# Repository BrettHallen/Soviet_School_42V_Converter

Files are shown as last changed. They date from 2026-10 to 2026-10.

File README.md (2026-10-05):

# Soviet School 42V Converter
Convert Australian 230VAC power to Soviet 42VAC for computers & calculators.<br>

The Soviet had a low-voltage (42V) power supply available that used a special plug & socket (розетка 42В).<br>

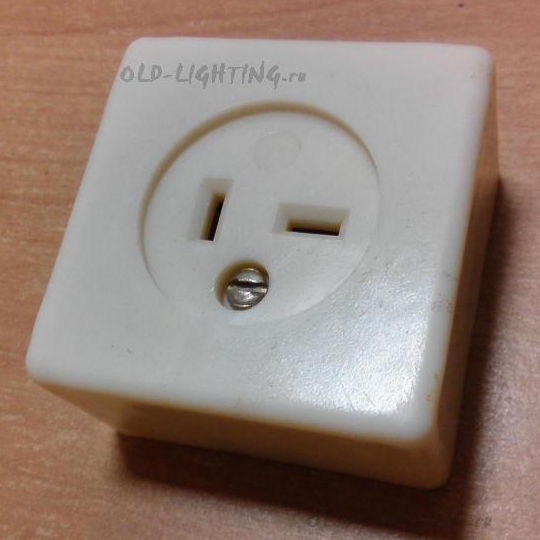
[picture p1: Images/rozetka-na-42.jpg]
Soviet LV socket


This was used by calculators such as the «Электроника МКШ-2» and computers such as the «Электроника МС0511».<br>

This appears similar to the Clipsal 402/32 (socket) and 492/32 (plug) available in Australia for low voltage requirements.<br>

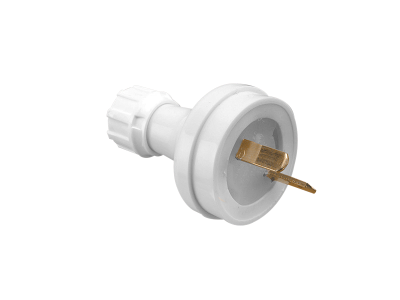
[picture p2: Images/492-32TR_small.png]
Clipsal plug


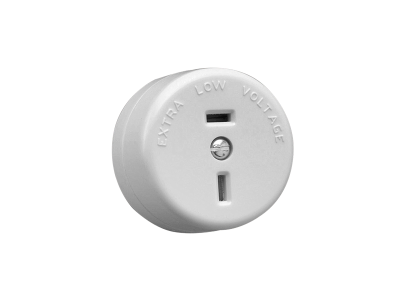
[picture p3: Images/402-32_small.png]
Clipsal socket


My idea was to create a simple 230VAC-to-42VAC step-down power supply with matching socket.<br>

My initial design will be using the Triad Magentics FP40-600 transformer.<br>

I'm not sure if the Soviet plug will fit the Australian socket, but the plug can always be replaced.<br>

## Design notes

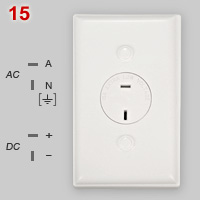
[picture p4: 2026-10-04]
Images/Clipsal_405-32_socket.jpg

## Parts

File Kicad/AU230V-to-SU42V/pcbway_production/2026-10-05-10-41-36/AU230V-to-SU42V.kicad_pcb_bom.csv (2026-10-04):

Designator | Quantity | Value | Footprint | Package | MPN | DNP | Mount_Type | Description | Height | Mouser Part Number | Mouser Price/Stock | Manufacturer_Name
F1 | 1 | 200mA T 250V | Fuseholder_Clip-5x20mm_Littelfuse_111_Inline_P20.00x5.00mm_D1.05mm_Horizontal |  |  |  | tht | Fuse
J1 | 1 | 230VAC Input | TJC1-2A |  |  |  | tht | C14 Plug, 10A max
J2 | 1 | 42VAC Output | TJC1-2A |  |  |  | tht | Generic connector, single row, 01x02, script generated (kicad-library-utils/schlib/autogen/connector/)
T1 | 1 | FP40-600 | FP40600 |  | FP40-600 |  | tht | Max. power 24VA, primary voltage 230V, secondary voltage 40Vct @ 600mA | 34.925 | 553-FP40-600 | https://mou.sr/4dQkbfw | Triad Magnetics

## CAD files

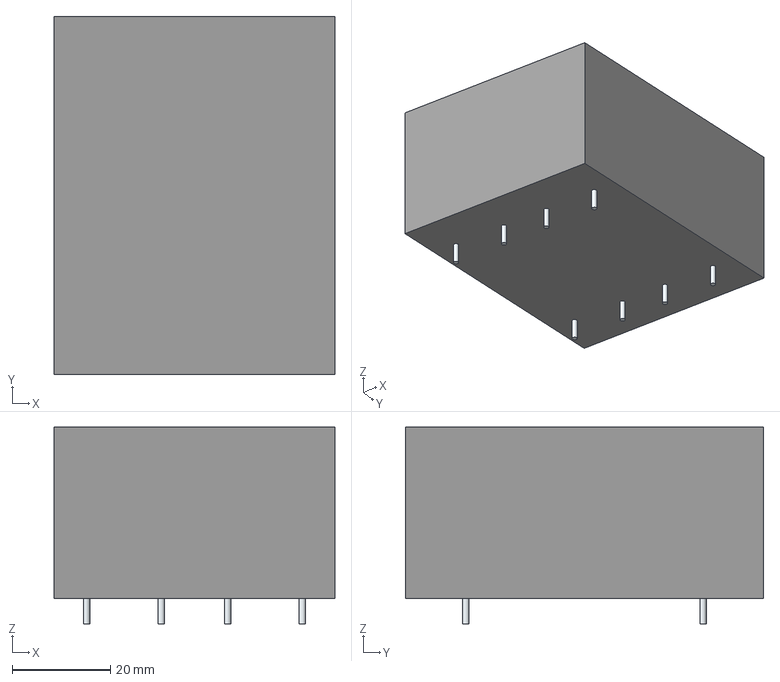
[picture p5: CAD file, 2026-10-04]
Kicad/LIB_FP40-600/FP40-600.stp
57.1 x 72.9 x 40.0 mm
Leads x 8

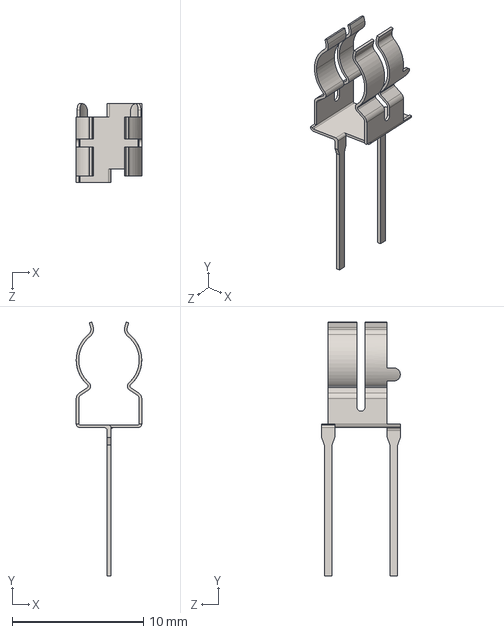
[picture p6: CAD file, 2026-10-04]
Kicad/51900001009.stp
5.00 x 19.4 x 6.00 mm

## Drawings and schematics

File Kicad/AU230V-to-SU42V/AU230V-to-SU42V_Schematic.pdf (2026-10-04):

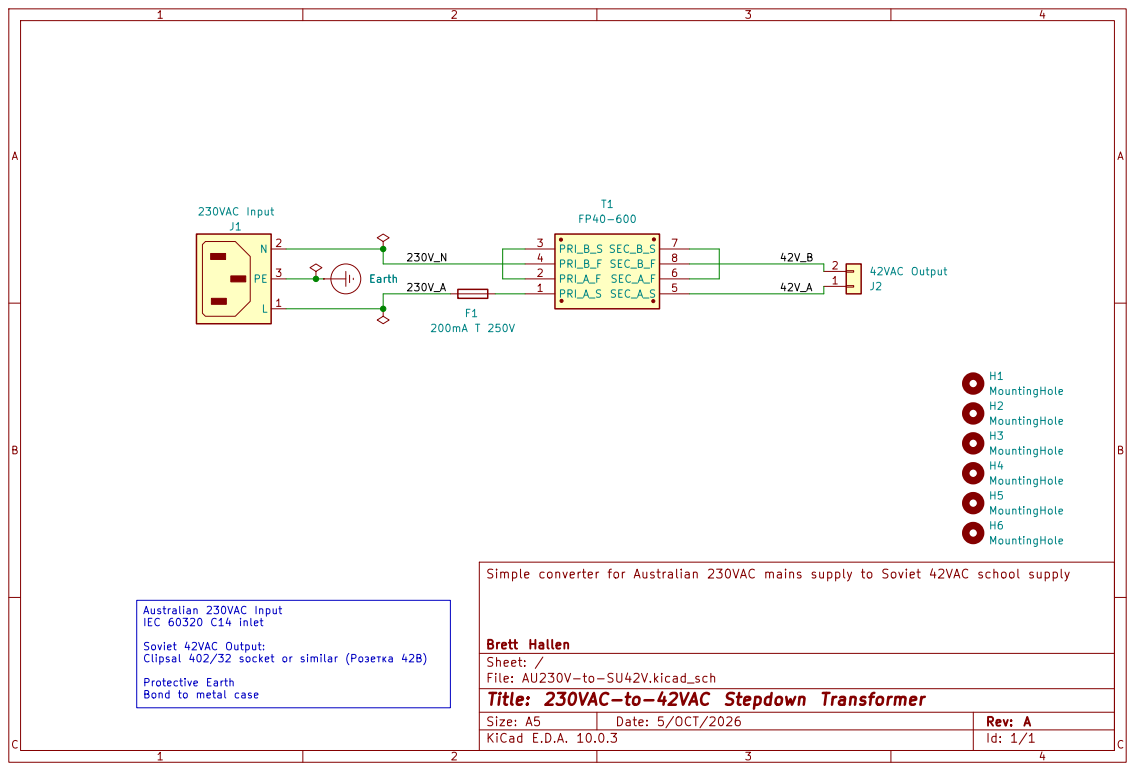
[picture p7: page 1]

Simple converter for Australian 230VAC mains supply to Soviet 42VAC school supply

Soviet 42VAC Output:
Clipsal 402/32 socket or similar (Розетка 42В)

Brett Hallen
Sheet: /
File: AU230V-to-SU42V.kicad_sch
Title: 230VAC-to-42VAC Stepdown Transformer

Size: A5 | Date: 5/OCT/2026 | Rev: A
KiCad E.D.A. 10.0.3 | | Id: 1/1

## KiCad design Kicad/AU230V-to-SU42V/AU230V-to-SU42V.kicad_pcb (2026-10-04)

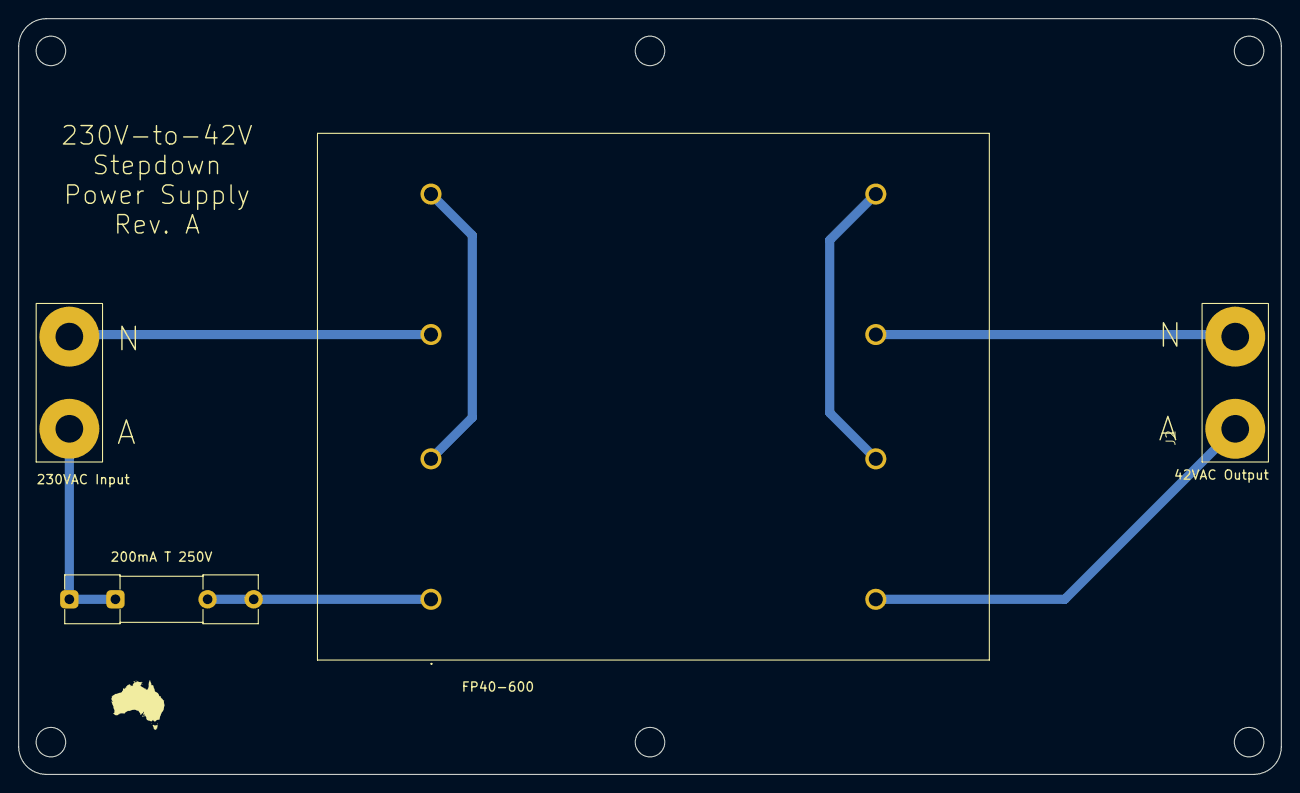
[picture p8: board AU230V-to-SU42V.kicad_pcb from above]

Board: 2 copper layers, 137.0 x 82.0 mm, 10 parts (0 on the bottom side), 7 nets.

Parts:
F1: 200mA T 250V; Fuseholder_Clip-5x20mm_Littelfuse_111_Inline_P20.00x5.00mm_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
H1, H2, H3, H4, H5, H6: MountingHole; MountingHole_3.2mm_M3
J1: 230VAC Input; TJC1-2A
J2: 42VAC Output; TJC1-2A
T1: FP40-600; FP40600

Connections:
/42V_A: J2.1, T1.5 (SEC_A_S)
/42V_B: J2.2, T1.8 (SEC_B_F)
/230V_A: F1.1, J1.1 (L)
/230V_N: J1.2 (N), T1.4 (PRI_B_F)
unnamed: T1.2 (PRI_A_F), T1.3 (PRI_B_S)
unnamed: F1.2, T1.1 (PRI_A_S)
unnamed: T1.6 (SEC_A_F), T1.7 (SEC_B_S)

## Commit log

2026-10-04 Initial PCB design
2026-11-04 Changed fuse holder type
2026-11-06 Updated design after testing
    Verified with Электроника МКШ-2.
    Line voltage input 240VAC, output with 100Ω resistor was 42.6VAC.
